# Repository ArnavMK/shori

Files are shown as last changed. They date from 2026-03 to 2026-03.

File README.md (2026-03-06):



**Shori PCB Layout:**



### What is this project?

Shori is a custom digital fx processor pcb for electric guitars. This is the heart of the modular project i am building called Wave forge (a solid state guitar amplifier )
And this is the first revision of the board!

This project comprises of three different printed circuit boards
1. Main power amp, preamp and I/O board: Shoyu (To be started)
2. The Digital FX processor: Shori (Rev 1 finished) 
3. The Screen controller board: Gamen (to be started)

here is the link for waveforge: [Here](https://github.com/ArnavMK/WaveForge)

### How to use it?

This is just rev 1 and is not manufactured yet, but this is a part of much larger multi board system and hence it needs to be connected to the other boards, through the two main connectors
The main ribbon connector for power and guitar audio from Shoyu. And the JST connector for the UART communication between the screen and shori. The screen has UI for controlling the parameters the digital fx like wet time modulation for delay and chorus. The screen will also have a waveform visualizer which is also be generated through shori.

### Why I made it

I have been playing electric for the past 11 years and never thought to build my own amp untill i met a friend profound in electronics and hardware design who inspired me into making my own. This board is the first step into putting a massive dent in WaveForge and i cant wait to finish it. Linked posts do not know what's coming for them.

I am pretty much nuking half the board for rev 2 now, after some peer roasting and friendly fire

### Project Pictures

There is no 3D encloser cad for shori yet! because that is the amp. Layout and 3D cad given on top of this page.

---

### Bill of Materials (BOM) FOR REV 1 ONLY !

This bom does not include the extra amount for each component, this is for only one shori board with perfect amount of compoenents!

*(A full `shori.csv` is also included in the root directory of this repository).*

| Component | Part Number | Quantity | Link | Cost (euro) |
| --- | --- | --- | --- | --- |
| Microcontroller | STM32F405RGT6 | 1 | [Link](https://www.digikey.ie/en/products/detail/stmicroelectronics/STM32F405RGT6/2754208) | 10.4 |
| Audio Codec | TI PCM3060 | 1 | [Link](https://www.digikey.com/en/models/1900019?tab=snapmagic) | 5.78 |
| Dual Audio Op-Amp | NE5532 | 1 | [Link](https://www.digikey.com/en/products/detail/texas-instruments/NE5532DR/499499) | 0.43 |
| Crystal Oscillator | 7M-25.000MAAE-T | 1 | [Link](https://www.digikey.ie/en/products/detail/txc-corporation/7M-25-000MAAE-T/3674351) | 0.59 |
| 3.3V LDO Regulator | AP2112K-3.3 | 1 | [Link](https://www.digikey.ie/en/products/detail/diodes-incorporated/ap2112k-3-3trg1/4470746) | 0.22 |
| 0805 capacitors (10uF) | 0805B475K160CC | 6 | [Link](https://www.digikey.com/en/products/detail/nextgen-components/0805B475K160CC/22601960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) | 0.34 |
| 0805 capacitors (100nF) | 0805B104K500BD | 11 | [Link](https://www.digikey.com/en/products/detail/nextgen-components/0805B104K500BD/15776052) | 0.078 |
| Custom PCB | 4-Layer FR4 | 5 | [Link](https://jlcpcb.com/) | 6.02 |
| JLCPCB shipping | DHL to ireland | - | [Link](https://jlcpcb.com/) | 26.95 |
| 0805 capacitors (2.2uF) | CL21B225KAFNNNE | 2 | [Link](https://www.digikey.com/en/products/detail/samsung-electro-mechanics/CL21B225KAFNNNE/3888612) | 0.12 |
| 0805 capacitors (1uF) | CL21B105KAFNNNE | 3 | [Link](https://www.digikey.com/en/products/detail/samsung-electro-mechanics/CL21B105KAFNNNE/3886724) | 0.10 |
| 0805 resistors (10K) | CR0805-FX-1002ELF | 7 | [Link](https://www.digikey.com/en/products/detail/bourns-inc/CR0805-FX-1002ELF/3593209) | 0.10 |

total price is around 78.64 euros.

### Notes for rev2

---

- Use the CS4272 audio codec for easier layout and routing with better top and bottom clipping range!
- Divide the main IDC connector into three sperate connectors for POWER (5V in), AUDIO_IN and AUDIO_OUT
- Add via fence and clear division between the analog and digital domains
- Add filtering for the audio input and output to the codec for optimal performance.

Thank you!

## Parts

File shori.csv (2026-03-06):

Reference | Qty | Value | DNP | Exclude from BOM | Exclude from Board | Footprint | Datasheet
C1 | 1 | 10μF |  |  |  | Capacitor_SMD:C_0805_2012Metric | ~
C2,C11 | 2 | 2.2uF |  |  |  | Capacitor_SMD:C_0805_2012Metric | ~
C3,C15,C17,C19,C22 | 5 | 10μF |  |  |  | Capacitor_SMD:C_1206_3216Metric | ~
C4,C6,C7,C8,C9,C12,C16,C18,C20,C24,C25 | 11 | 100nF |  |  |  | Capacitor_SMD:C_0805_2012Metric | ~
C5,C26,C27 | 3 | 1uF |  |  |  | Capacitor_SMD:C_0805_2012Metric | ~
C10,C29 | 2 | 10uF |  |  |  | Capacitor_SMD:C_1206_3216Metric | ~
C13,C14 | 2 | 18pF |  |  |  | Capacitor_SMD:C_0805_2012Metric | ~
C21,C23 | 2 | 4.7μF |  |  |  | Capacitor_SMD:C_0805_2012Metric | ~
C28 | 1 | 100pF |  |  |  | Capacitor_SMD:C_0805_2012Metric | ~
D1 | 1 | D_Schottky |  |  |  | Diode_SMD:D_SOD-123 | ~
FB1,FB2 | 2 | FerriteBead |  |  |  | Inductor_SMD:L_0805_2012Metric | ~
H1,H2,H3,H4 | 4 | MountingHole |  | Excluded from BOM |  | MountingHole:MountingHole_3mm | ~
J1 | 1 | Conn_02x03_Top_Bottom |  |  |  | Connector_IDC:IDC-Header_2x03_P2.54mm_Vertical | ~
J2 | 1 | SWD_Header |  |  |  | Connector_PinHeader_2.54mm:PinHeader_1x04_P2.54mm_Vertical | ~
J3 | 1 | UART_Header |  |  |  | Connector_JST:JST_XH_B4B-XH-A_1x04_P2.50mm_Vertical | ~
J5 | 1 | AudioJack3 |  |  |  | Connector_Audio:Jack_3.5mm_CUI_SJ1-3523N_Horizontal | ~
R1,R4,R5,R6,R7,R8,R9 | 7 | 10K |  |  |  | Resistor_SMD:R_0805_2012Metric | ~
R2 | 1 | 2.2K |  |  |  | Resistor_SMD:R_0805_2012Metric | ~
R3 | 1 | 2.2k |  |  |  | Resistor_SMD:R_0805_2012Metric | ~
U1 | 1 | STM32F405RGT6 |  |  |  | My footprints:QFP50P1200X1200X160-64N
U2 | 1 | AP2112K-3.3 |  |  |  | Package_TO_SOT_SMD:SOT-23-5 | https://www.diodes.com/assets/Datasheets/AP2112.pdf
U3 | 1 | PCM3060PWR |  |  |  | My footprints:SOP65P640X120-28N
U4 | 1 | NE5532 |  |  |  | Package_SO:SOIC-8_3.9x4.9mm_P1.27mm | http://www.ti.com/lit/ds/symlink/ne5532.pdf
Y1 | 1 | 16MHz |  |  |  | Crystal:Crystal_SMD_3225-4Pin_3.2x2.5mm_HandSoldering | ~

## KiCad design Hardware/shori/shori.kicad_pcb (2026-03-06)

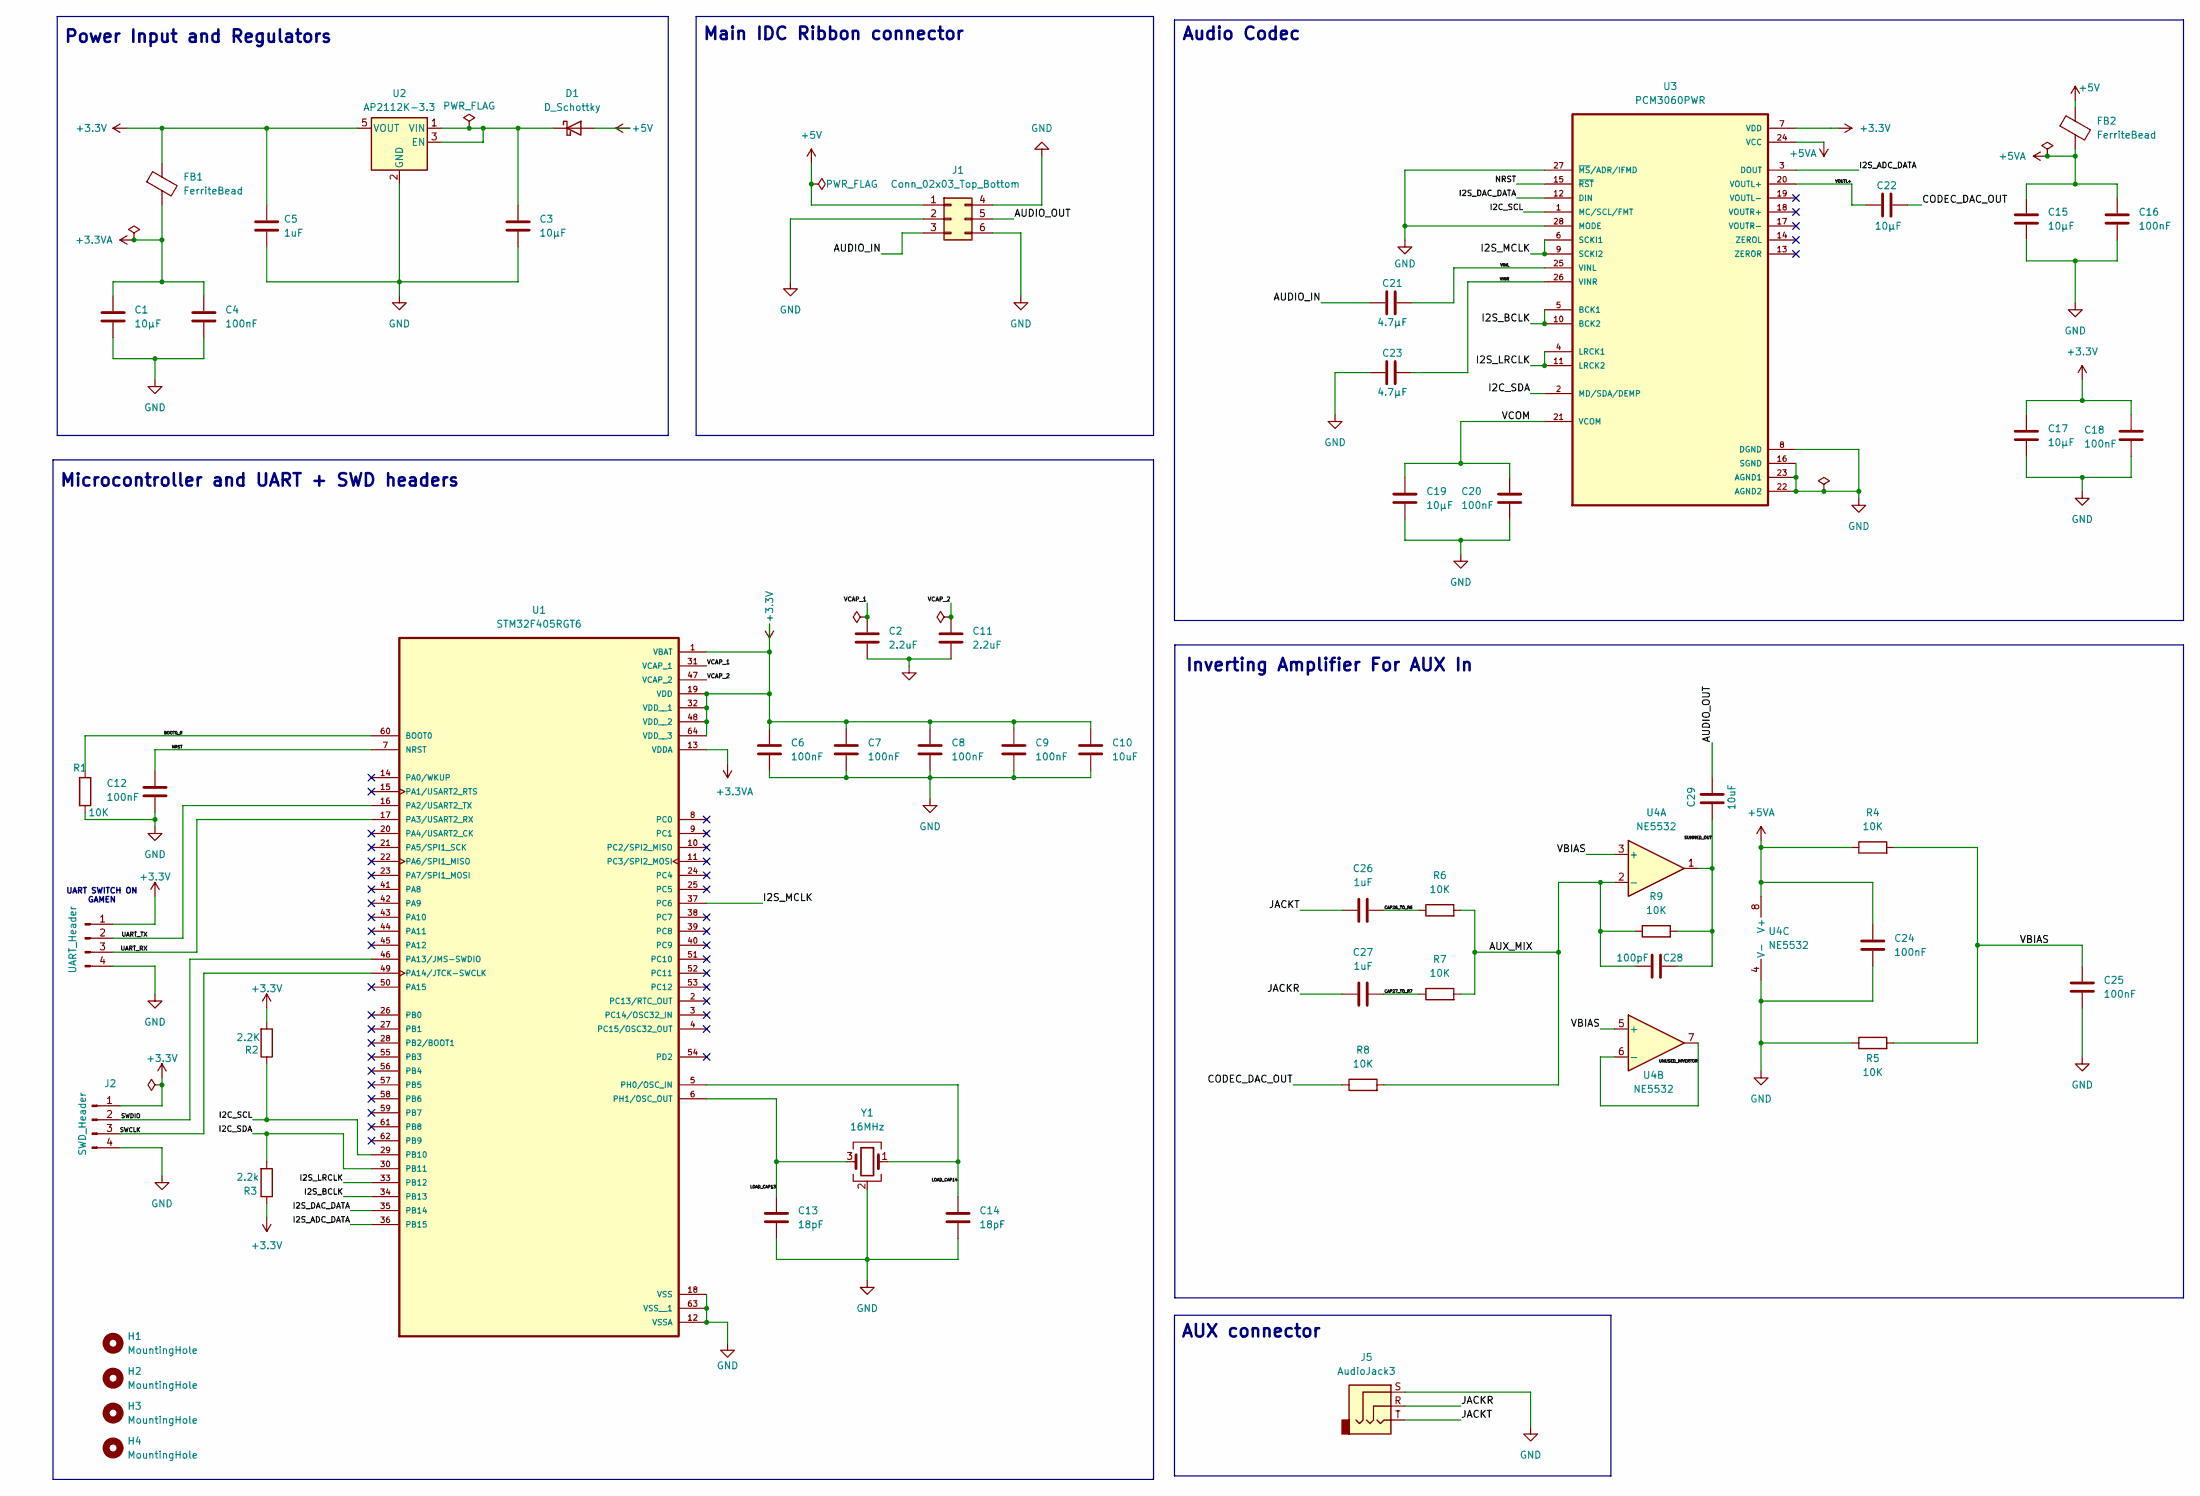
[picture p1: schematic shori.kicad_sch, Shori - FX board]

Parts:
C1: 10μF; C_0805_2012Metric
C2, C11: 2.2uF; C_0805_2012Metric
C3, C15, C17, C19, C22: 10μF; C_1206_3216Metric
C4, C6, C7, C8, C9, C12, C16, C18, C20, C24, C25: 100nF; C_0805_2012Metric
C5, C26, C27: 1uF; C_0805_2012Metric
C10, C29: 10uF; C_1206_3216Metric
C13, C14: 18pF; C_0805_2012Metric
C21, C23: 4.7μF; C_0805_2012Metric
C28: 100pF; C_0805_2012Metric
D1: D_Schottky; D_SOD-123
FB1, FB2: FerriteBead; L_0805_2012Metric
H1, H2, H3, H4: MountingHole; MountingHole_3mm
J1: Conn_02x03_Top_Bottom; IDC-Header_2x03_P2.54mm_Vertical
J2: SWD_Header; PinHeader_1x04_P2.54mm_Vertical
J3: UART_Header; JST_XH_B4B-XH-A_1x04_P2.50mm_Vertical
J5: AudioJack3; Jack_3.5mm_CUI_SJ1-3523N_Horizontal
R1, R4, R5, R6, R7, R8, R9: 10K; R_0805_2012Metric
R2: 2.2K; R_0805_2012Metric
R3: 2.2k; R_0805_2012Metric
U1: STM32F405RGT6; QFP50P1200X1200X160-64N; PARTREV LTR
U2: AP2112K-3.3; SOT-23-5
U3: PCM3060PWR; SOP65P640X120-28N
U4: NE5532; SOIC-8_3.9x4.9mm_P1.27mm
Y1: 16MHz; Crystal_SMD_3225-4Pin_3.2x2.5mm_HandSoldering

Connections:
+3.3V: C5.1, C6.1, C7.1, C8.1, C9.1, C10.1, C17.1, C18.1, FB1.1, J2.1, J3.1, R2.2, R3.1, U1.1 (VBAT), U1.19 (VDD), U1.32 (VDD__1), U1.48 (VDD__2), U1.64 (VDD__3), U2.5 (VOUT), U3.7 (VDD); also elsewhere on the board
+3.3VA: C1.1, C4.1, FB1.2, U1.13 (VDDA)
+5V: D1.2 (A), FB2.1, J1.1; also elsewhere on the board
+5VA: C15.1, C16.1, C24.1, FB2.2, R4.1, U3.24 (VCC), U4.8 (V+)
/AUDIO_IN: C21.2, J1.3; also elsewhere on the board
/AUDIO_OUT: C29.2, J1.5; also elsewhere on the board
/AUX_MIX: C28.1, R6.2, R7.2, R8.2, R9.1, U4.2 (-)
/BOOT0_R: R1.1, U1.60 (BOOT0)
/CAP26_TO_R6: C26.2, R6.1
/CAP27_TO_R7: C27.2, R7.1
/CODEC_DAC_OUT: C22.2, R8.1
/I2C_SCL: R2.1, U1.29 (PB10), U3.1 (MC/SCL/FMT)
/I2C_SDA: R3.2, U1.30 (PB11), U3.2 (MD/SDA/DEMP)
/I2S_ADC_DATA: U1.36 (PB15), U3.3 (DOUT)
/I2S_BCLK: U1.34 (PB13), U3.5 (BCK1), U3.10 (BCK2)
/I2S_DAC_DATA: U1.35 (PB14), U3.12 (DIN)
/I2S_LRCLK: U1.33 (PB12), U3.4 (LRCK1), U3.11 (LRCK2)
/I2S_MCLK: U1.37 (PC6), U3.6 (SCKI1), U3.9 (SCKI2)
/JACKR: C27.1, J5.R; also elsewhere on the board
/JACKT: C26.1, J5.T; also elsewhere on the board
/LOAD_CAP13: C13.1, U1.6 (PH1/OSC_OUT), Y1.3
/LOAD_CAP14: C14.1, U1.5 (PH0/OSC_IN), Y1.1
/NRST: C12.1, U1.7 (NRST), U3.15 (~RST)
/SUMMED_OUT: C28.2, C29.1, R9.2, U4.1
/SWCLK: J2.3, U1.49 (PA14/JTCK-SWCLK); also elsewhere on the board
/SWDIO: J2.2, U1.46 (PA13/JMS-SWDIO); also elsewhere on the board
/UART_RX: J3.3, U1.17 (PA3/USART2_RX); also elsewhere on the board
/UART_TX: J3.2, U1.16 (PA2/USART2_TX); also elsewhere on the board
/UNUSED_INVERTOR: U4.6 (-), U4.7
/VBIAS: C25.1, R4.2, R5.2, U4.3 (+), U4.5 (+)
/VCAP_1: C2.2, U1.31 (VCAP_1)
/VCAP_2: C11.2, U1.47 (VCAP_2)
/VCOM: C19.1, C20.1, U3.21 (VCOM)
/VINL: C21.1, U3.25 (VINL)
/VINR: C23.1, U3.26 (VINR)
/VOUTL+: C22.1, U3.20 (VOUTL+)
GND: C1.2, C2.1, C3.2, C4.2, C5.2, C6.2, C7.2, C8.2, C9.2, C10.2, C11.1, C12.2, C13.2, C14.2, C15.2, C16.2, C17.2, C18.2, C19.2, C20.2, C23.2, C24.2, C25.2, J1.2, J1.4, J1.6, J2.4, J3.4, J5.S, R1.2, R5.1, U1.12 (VSSA), U1.18 (VSS), U1.63 (VSS__1), U2.2 (GND), U3.8 (DGND), U3.16 (SGND), U3.22 (AGND2), U3.23 (AGND1), U3.27 (~MS/ADR/IFMD), U3.28 (MODE), U4.4 (V-), Y1.2 (G), Y1.4 (G); also elsewhere on the board
unnamed: C3.1, D1.1 (K), U2.1 (VIN), U2.3 (EN)

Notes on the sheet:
Audio Codec
Inverting Amplifier For AUX In
Microcontroller and UART + SWD headers
Power Input and Regulators
Main IDC Ribbon connector
UART SWITCH ON GAMEN
AUX connector

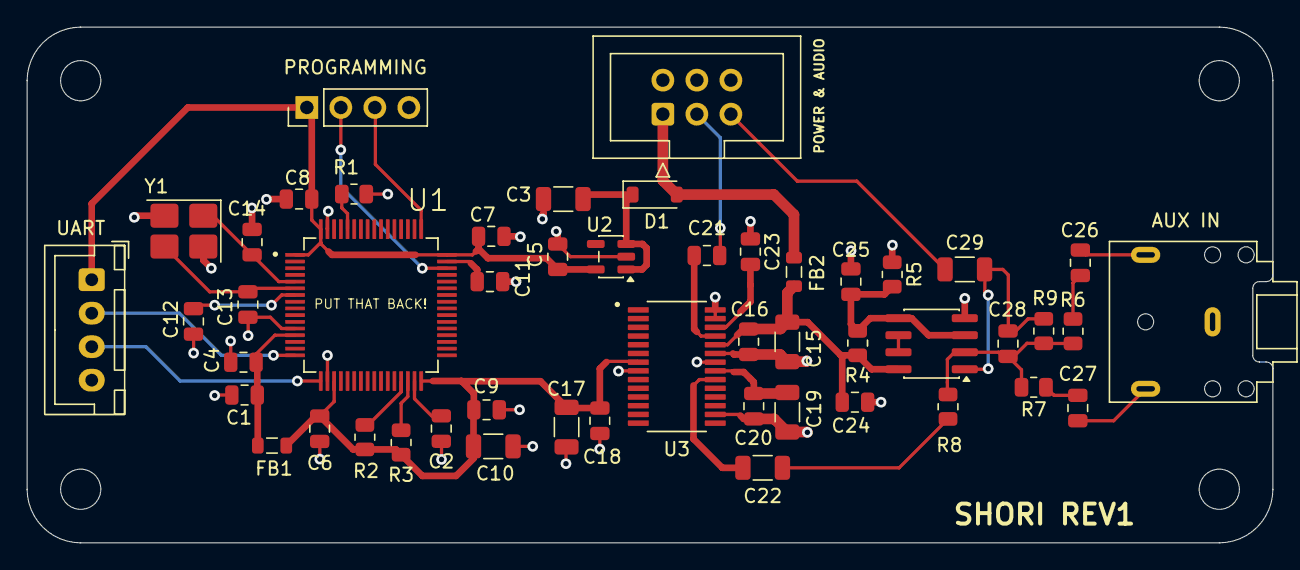
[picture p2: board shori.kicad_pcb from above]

Board: 4 copper layers, 93.0 x 38.5 mm, 54 parts (0 on the bottom side), 38 nets.

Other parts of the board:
AUX IN: AudioJack3; Jack_3.5mm_CUI_SJ1-3523N_Horizontal
POWER & AUDIO: Conn_02x03_Top_Bottom; IDC-Header_2x03_P2.54mm_Vertical
PROGRAMMING: SWD_Header; PinHeader_1x04_P2.54mm_Vertical
UART: UART_Header; JST_XH_B4B-XH-A_1x04_P2.50mm_Vertical

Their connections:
+3.3V: PROGRAMMING.1, UART.1; also elsewhere on the board
+5V: POWER & AUDIO.1; also elsewhere on the board
/AUDIO_IN: POWER & AUDIO.3; also elsewhere on the board
/AUDIO_OUT: POWER & AUDIO.5; also elsewhere on the board
/JACKR: AUX IN.R; also elsewhere on the board
/JACKT: AUX IN.T; also elsewhere on the board
/SWCLK: PROGRAMMING.3; also elsewhere on the board
/SWDIO: PROGRAMMING.2; also elsewhere on the board
/UART_RX: UART.3; also elsewhere on the board
/UART_TX: UART.2; also elsewhere on the board
GND: AUX IN.S, POWER & AUDIO.2, POWER & AUDIO.4, POWER & AUDIO.6, PROGRAMMING.4, UART.4; also elsewhere on the board

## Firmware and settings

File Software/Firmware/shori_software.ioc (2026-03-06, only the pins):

Mcu.UserName=STM32F405RGTx
PB10.Signal=I2C2_SCL
PB11.Signal=I2C2_SDA
PB12.Signal=I2S2_WS
PB13.Signal=I2S2_CK
PB14.Signal=I2S2_ext_SD
PB15.Signal=I2S2_SD
PC6.Signal=I2S2_MCK
PH0-OSC_IN.Signal=RCC_OSC_IN
PH1-OSC_OUT.Signal=RCC_OSC_OUT

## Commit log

2026-03-06 imported shori from waveforge
    [shori.csv, shori.kicad_pcb, shori.kicad_sch]
2026-03-06 Initialize README with project overview and BOM
    Added project details, BOM, and notes for revision 2.
